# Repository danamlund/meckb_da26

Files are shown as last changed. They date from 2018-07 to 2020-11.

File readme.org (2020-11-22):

A 26-key keyboard with 3d printed case and [[https://github.com/qmk/qmk_firmware][qmk firmware]]

* Features
 - 26 keys
 - Layers within layers
 - Tetris
 - Minesweeper
 - Basic

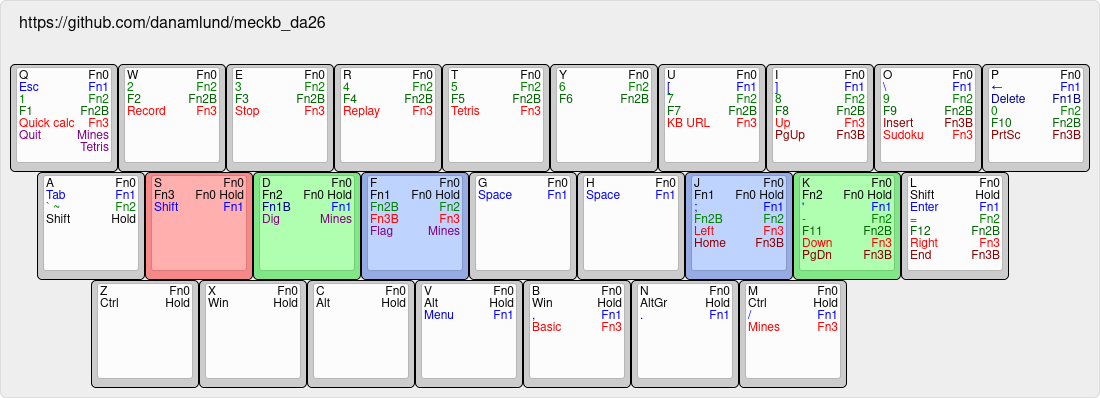
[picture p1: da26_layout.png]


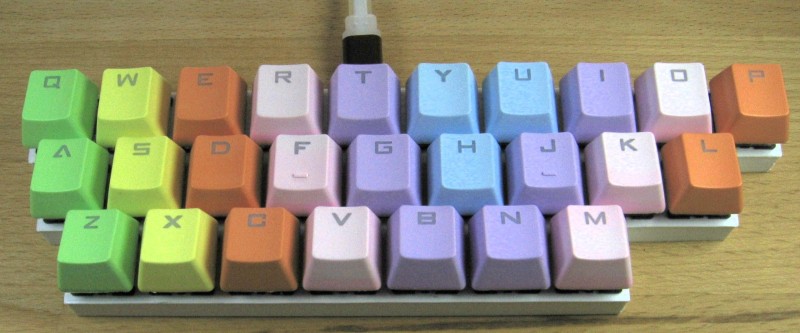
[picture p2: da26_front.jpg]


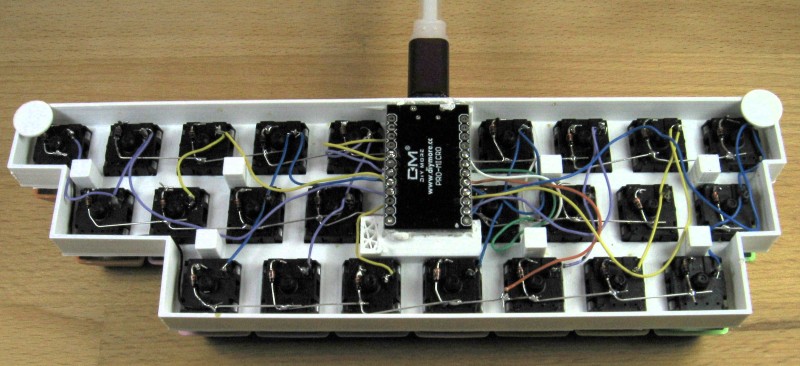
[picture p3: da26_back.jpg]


* Common key combinations
 - ALT F4: C (Alt), K (Fn2), J (Fn2B), R (F4)
 - Ctrl C: Z (Ctrl), C
 - Ctrl Z: M (Ctrl), Z
 - Shift Enter: A (Shift), F (Fn1), L (Enter)
 - AltGr ': N (AltGr), F (Fn1), K (')
 - Alt Tab: C (Alt), J (Fn1), A (Tab)
 - Shift Alt Tab: C (Alt), J (Fn1), L (Shift), A (Tab)
 - Ctrl PgDn: Z (Ctrl), S (Fn3), F (Fn3B), K (PgDn)
 - C-x C-s: Z (Ctrl), X (x), release X, S (s)
 - :q!<enter>: A (Shift), F (Fn1), J (;), release, Q (q), release, F (Fn1), L (Enter)

* Tetris
 - When playing tetris the keyboard is stuck in FN3
 - Use ijkl keys to move/rotate/drop
 - Press ESC to quit

* Minesweeper
 - Use ijkl keys to move cursor around
 - Press d to dig for a mine
 - Press f to flag square as a mine
 - Press Esc to quit
 - 16x16 grid with 40 mines (Intermediate in windows minesweeper)

* Basic
 - [[https://en.wikipedia.org/wiki/Tiny_BASIC][Tiny BASIC]]
 - [[http://hamsterworks.co.nz/mediawiki/index.php/Arduino_Basic][Arduino Basic / Tiny Basic C by Michael Field and Scott Lawrence]]
   - Simpler sibling of [[https://github.com/BleuLlama/TinyBasicPlus][TinyBasic Plus]]
 - Press ESC to break out of infinite loops
 - Type 'bye' to quit
 - Ignores movement keys except for backspace
 - Uses US layout
 - 1024 bytes memory (866 free after reserved variable storage)
 - all numbers are float
 - Executes 1 instruction per 50 ms
 - When typed keys stop working you are out of memory
 - Type 'mem' to see memory left
 - ncurses version in tinybasic_test/
 - quick calc calls basic, stores result in a, and prints it

* keyboard-layout-editor.com
 - http://www.keyboard-layout-editor.com
** All layers in one
#+HTML: <a href="http://www.keyboard-layout-editor.com/##@@_f:5&w:10&d:true;&=https/:////github.com//danamlund//meckb/_da26;&@_f:3&w:2&h:2;&=Q%3Cbr//%3E%3Cfont%20color/=blue%3EEsc%3C//font%3E%3Cbr//%3E%3Cfont%20color/=green%3E1%3C//font%3E%3Cbr//%3E%3Cfont%20color/=darkgreen%3EF1%3C//font%3E%3Cbr//%3E%3Cfont%20color/=red%3EQuick%20calc%3C//font%3E%3Cbr//%3E%3Cfont%20color/=purple%3EQuit%3C//font%3E%0A%0AFn0%3Cbr//%3E%3Cfont%20color/=blue%3EFn1%3C//font%3E%3Cbr//%3E%3Cfont%20color/=green%3EFn2%3C//font%3E%3Cbr//%3E%3Cfont%20color/=darkgreen%3EFn2B%3C//font%3E%3Cbr//%3E%3Cfont%20color/=red%3EFn3%3C//font%3E%3Cbr//%3E%3Cfont%20color/=purple%3EMines%3C//font%3E%3Cbr//%3E%3Cfont%20color/=purple%3ETetris%3C//font%3E&_w:2&h:2;&=W%3Cbr//%3E%3Cfont%20color/=green%3E2%3C//font%3E%3Cbr//%3E%3Cfont%20color/=darkgreen%3EF2%3C//font%3E%3Cbr//%3E%3Cfont%20color/=red%3ERecord%3C//font%3E%0A%0AFn0%3Cbr//%3E%3Cfont%20color/=green%3EFn2%3C//font%3E%3Cbr//%3E%3Cfont%20color/=darkgreen%3EFn2B%3C//font%3E%3Cbr//%3E%3Cfont%20color/=red%3EFn3%3C//font%3E&_w:2&h:2;&=E%3Cbr//%3E%3Cfont%20color/=green%3E3%3C//font%3E%3Cbr//%3E%3Cfont%20color/=darkgreen%3EF3%3C//font%3E%3Cbr//%3E%3Cfont%20color/=red%3EStop%3C//font%3E%0A%0AFn0%3Cbr//%3E%3Cfont%20color/=green%3EFn2%3C//font%3E%3Cbr//%3E%3Cfont%20color/=darkgreen%3EFn2B%3C//font%3E%3Cbr//%3E%3Cfont%20color/=red%3EFn3%3C//font%3E&_w:2&h:2;&=R%3Cbr//%3E%3Cfont%20color/=green%3E4%3C//font%3E%3Cbr//%3E%3Cfont%20color/=darkgreen%3EF4%3C//font%3E%3Cbr//%3E%3Cfont%20color/=red%3EReplay%3C//font%3E%0A%0AFn0%3Cbr//%3E%3Cfont%20color/=green%3EFn2%3C//font%3E%3Cbr//%3E%3Cfont%20color/=darkgreen%3EFn2B%3C//font%3E%3Cbr//%3E%3Cfont%20color/=red%3EFn3%3C//font%3E&_w:2&h:2;&=T%3Cbr//%3E%3Cfont%20color/=green%3E5%3C//font%3E%3Cbr//%3E%3Cfont%20color/=darkgreen%3EF5%3C//font%3E%3Cbr//%3E%3Cfont%20color/=red%3ETetris%3C//font%3E%0A%0AFn0%3Cbr//%3E%3Cfont%20color/=green%3EFn2%3C//font%3E%3Cbr//%3E%3Cfont%20color/=darkgreen%3EFn2B%3C//font%3E%3Cbr//%3E%3Cfont%20color/=red%3EFn3%3C//font%3E&_w:2&h:2;&=Y%3Cbr//%3E%3Cfont%20color/=green%3E6%3C//font%3E%3Cbr//%3E%3Cfont%20color/=darkgreen%3EF6%3C//font%3E%0A%0AFn0%3Cbr//%3E%3Cfont%20color/=green%3EFn2%3C//font%3E%3Cbr//%3E%3Cfont%20color/=darkgreen%3EFn2B%3C//font%3E&_w:2&h:2;&=U%3Cbr//%3E%3Cfont%20color/=blue%3E%5B%3C//font%3E%3Cbr//%3E%3Cfont%20color/=green%3E7%3C//font%3E%3Cbr//%3E%3Cfont%20color/=darkgreen%3EF7%3C//font%3E%3Cbr//%3E%3Cfont%20color/=red%3EKB%20URL%3C//font%3E%0A%0AFn0%3Cbr//%3E%3Cfont%20color/=blue%3EFn1%3C//font%3E%3Cbr//%3E%3Cfont%20color/=green%3EFn2%3C//font%3E%3Cbr//%3E%3Cfont%20color/=darkgreen%3EFn2B%3C//font%3E%3Cbr//%3E%3Cfont%20color/=red%3EFn3%3C//font%3E&_w:2&h:2;&=I%3Cbr//%3E%3Cfont%20color/=blue%3E%5D%3C//font%3E%3Cbr//%3E%3Cfont%20color/=green%3E8%3C//font%3E%3Cbr//%3E%3Cfont%20color/=darkgreen%3EF8%3C//font%3E%3Cbr//%3E%3Cfont%20color/=red%3EUp%3C//font%3E%3Cbr//%3E%3Cfont%20color/=darkred%3EPgUp%3C//font%3E%0A%0AFn0%3Cbr//%3E%3Cfont%20color/=blue%3EFn1%3C//font%3E%3Cbr//%3E%3Cfont%20color/=green%3EFn2%3C//font%3E%3Cbr//%3E%3Cfont%20color/=darkgreen%3EFn2B%3C//font%3E%3Cbr//%3E%3Cfont%20color/=red%3EFn3%3C//font%3E%3Cbr//%3E%3Cfont%20color/=darkred%3EFn3B%3C//font%3E&_w:2&h:2;&=O%3Cbr//%3E%3Cfont%20color/=blue%3E%5C%3C//font%3E%3Cbr//%3E%3Cfont%20color/=green%3E9%3C//font%3E%3Cbr//%3E%3Cfont%20color/=darkgreen%3EF9%3C//font%3E%3Cbr//%3E%3Cfont%20color/=darkred%3EInsert%3C//font%3E%3Cbr//%3E%3Cfont%20color/=red%3ESudoku%3C//font%3E%0A%0AFn0%3Cbr//%3E%3Cfont%20color/=blue%3EFn1%3C//font%3E%3Cbr//%3E%3Cfont%20color/=green%3EFn2%3C//font%3E%3Cbr//%3E%3Cfont%20color/=darkgreen%3EFn2B%3C//font%3E%3Cbr//%3E%3Cfont%20color/=darkred%3EFn3B%3C//font%3E%3Cbr//%3E%3Cfont%20color/=red%3EFn3%3C//font%3E&_w:2&h:2;&=P%3Cbr//%3E%3Cfont%20color/=blue%3E%E2%86%90%3C//font%3E%3Cbr//%3E%3Cfont%20color/=darkblue%3EDelete%3C//font%3E%3Cbr//%3E%3Cfont%20color/=green%3E0%3C//font%3E%3Cbr//%3E%3Cfont%20color/=darkgreen%3EF10%3C//font%3E%3Cbr//%3E%3Cfont%20color/=darkred%3EPrtSc%3C//font%3E%0A%0AFn0%3Cbr//%3E%3Cfont%20color/=blue%3EFn1%3C//font%3E%3Cbr//%3E%3Cfont%20color/=darkblue%3EFn1B%3C//font%3E%3Cbr//%3E%3Cfont%20color/=green%3EFn2%3C//font%3E%3Cbr//%3E%3Cfont%20color/=darkgreen%3EFn2B%3C//font%3E%3Cbr//%3E%3Cfont%20color/=darkred%3EFn3B%3C//font%3E;&@_y:1&x:0.5&w:2&h:2;&=A%3Cbr//%3E%3Cfont%20color/=blue%3ETab%3C//font%3E%3Cbr//%3E%3Cfont%20color/=green%3E%60%20~%3C//font%3E%3Cbr//%3EShift%0A%0AFn0%3Cbr//%3E%3Cfont%20color/=blue%3EFn1%3C//font%3E%3Cbr//%3E%3Cfont%20color/=green%3EFn2%3C//font%3E%3Cbr%3EHold&_w:2&h:2&c=#f78888;&=S%3Cbr//%3EFn3%3Cbr//%3E%3Cfont%20color/=blue%3EShift%3C//font%3E%0A%0AFn0%3Cbr//%3EFn0%20Hold%3Cbr//%3E%3Cfont%20color/=blue%3EFn1%3C//font%3E&_w:2&h:2&c=#81e685;&=D%3Cbr//%3EFn2%3Cbr//%3E%3Cfont%20color/=darkblue%3EFn1B%3C//font%3E%3Cbr//%3E%3Cfont%20color/=purple%3EDig%3C//font%3E%0A%0AFn0%3Cbr//%3EFn0%20Hold%3Cbr//%3E%3Cfont%20color/=blue%3EFn1%3C//font%3E%3Cbr//%3E%3Cfont%20color/=purple%3EMines%3C//font%3E&_w:2&h:2&c=#96abe3;&=F%3Cbr//%3EFn1%3Cbr//%3E%3Cfont%20color/=green%3EFn2B%3C//font%3E%3Cbr//%3E%3Cfont%20color/=red%3EFn3B%3C//font%3E%3Cbr//%3E%3Cfont%20color/=purple%3EFlag%3C//font%3E%0A%0AFn0%3Cbr//%3EFn0%20Hold%3Cbr//%3E%3Cfont%20color/=green%3EFn2%3C//font%3E%3Cbr//%3E%3Cfont%20color/=red%3EFn3%3C//font%3E%3Cbr//%3E%3Cfont%20color/=purple%3EMines%3C//font%3E&_w:2&h:2&c=#cccccc;&=G%3Cbr//%3E%3Cfont%20color/=blue%3ESpace%3C//font%3E%0A%0AFn0%3Cbr//%3E%3Cfont%20color/=blue%3EFn1%3C//font%3E&_w:2&h:2;&=H%3Cbr//%3E%3Cfont%20color/=blue%3ESpace%3C//font%3E%0A%0AFn0%3Cbr//%3E%3Cfont%20color/=blue%3EFn1%3C//font%3E&_w:2&h:2&c=#96abe3;&=J%3Cbr//%3EFn1%3Cbr//%3E%3Cfont%20color/=blue%3E/;%3C//font%3E%3Cbr//%3E%3Cfont%20color/=green%3EFn2B%3C//font%3E%3Cbr//%3E%3Cfont%20color/=red%3ELeft%3C//font%3E%3Cbr//%3E%3Cfont%20color/=darkred%3EHome%3C//font%3E%0A%0AFn0%3Cbr//%3EFn0%20Hold%3Cbr//%3E%3Cfont%20color/=blue%3EFn1%3C//font%3E%3Cbr//%3E%3Cfont%20color/=green%3EFn2%3C//font%3E%3Cbr//%3E%3Cfont%20color/=red%3EFn3%3C//font%3E%3Cbr//%3E%3Cfont%20color/=darkred%3EFn3B%3C//font%3E&_w:2&h:2&c=#81e685;&=K%3Cbr//%3EFn2%3Cbr//%3E%3Cfont%20color/=blue%3E'%3C//font%3E%3Cbr//%3E%3Cfont%20color/=green%3E-%3C//font%3E%3Cbr//%3E%3Cfont%20color/=darkgreen%3EF11%3C//font%3E%3Cbr//%3E%3Cfont%20color/=red%3EDown%3C//font%3E%3Cbr//%3E%3Cfont%20color/=darkred%3EPgDn%3C//font%3E%0A%0AFn0%3Cbr//%3EFn0%20Hold%3Cbr//%3E%3Cfont%20color/=blue%3EFn1%3C//font%3E%3Cbr//%3E%3Cfont%20color/=green%3EFn2%3C//font%3E%3Cbr//%3E%3Cfont%20color/=darkgreen%3EFn2B%3C//font%3E%3Cbr//%3E%3Cfont%20color/=red%3EFn3%3C//font%3E%3Cbr//%3E%3Cfont%20color/=darkred%3EFn3B%3C//font%3E&_w:2&h:2&c=#cccccc;&=L%3Cbr//%3EShift%3Cbr//%3E%3Cfont%20color/=blue%3EEnter%3C//font%3E%3Cbr//%3E%3Cfont%20color/=green%3E/=%3C//font%3E%3Cbr//%3E%3Cfont%20color/=darkgreen%3EF12%3C//font%3E%3Cbr//%3E%3Cfont%20color/=red%3ERight%3C//font%3E%3Cbr//%3E%3Cfont%20color/=darkred%3EEnd%3C//font%3E%0A%0AFn0%3Cbr//%3EHold%3Cbr//%3E%3Cfont%20color/=blue%3EFn1%3C//font%3E%3Cbr//%3E%3Cfont%20color/=green%3EFn2%3C//font%3E%3Cbr//%3E%3Cfont%20color/=darkgreen%3EFn2B%3C//font%3E%3Cbr//%3E%3Cfont%20color/=red%3EFn3%3C//font%3E%3Cbr//%3E%3Cfont%20color/=darkred%3EFn3B%3C//font%3E;&@_y:1&x:1.5&w:2&h:2;&=Z%3Cbr//%3ECtrl%0A%0AFn0%3Cbr//%3EHold&_w:2&h:2;&=X%3Cbr//%3EWin%0A%0AFn0%3Cbr//%3EHold&_w:2&h:2;&=C%3Cbr//%3EAlt%0A%0AFn0%3Cbr//%3EHold&_w:2&h:2;&=V%3Cbr//%3EAlt%3Cbr//%3E%3Cfont%20color/=blue%3EMenu%3C//font%3E%0A%0AFn0%3Cbr//%3EHold%3Cbr//%3E%3Cfont%20color/=blue%3EFn1%3C//font%3E&_w:2&h:2;&=B%3Cbr//%3EWin%3Cbr//%3E%3Cfont%20color/=blue%3E,%3C//font%3E%3Cbr//%3E%3Cfont%20color/=red%3EBasic%3C//font%3E%0A%0AFn0%3Cbr//%3EHold%3Cbr//%3E%3Cfont%20color/=blue%3EFn1%3C//font%3E%3Cbr//%3E%3Cfont%20color/=red%3EFn3%3C//font%3E&_w:2&h:2;&=N%3Cbr//%3EAltGr%3Cbr//%3E%3Cfont%20color/=blue%3E.%3C//font%3E%0A%0AFn0%3Cbr//%3EHold%3Cbr//%3E%3Cfont%20color/=blue%3EFn1%3C//font%3E&_w:2&h:2;&=M%3Cbr//%3ECtrl%3Cbr//%3E%3Cfont%20color/=blue%3E//%3C//font%3E%3Cbr//%3E%3Cfont%20color/=red%3EMines%3C//font%3E%0A%0AFn0%3Cbr//%3EHold%3Cbr//%3E%3Cfont%20color/=blue%3EFn1%3C//font%3E%3Cbr//%3E%3Cfont%20color/=red%3EFn3%3C//font%3E">da26 keyboard-layout-editor.com</a>
#+BEGIN_EXAMPLE
[{f:5,w:10,d:true},"https://github.com/danamlund/meckb_da26"],
[{f:3,w:2,h:2},"Q<br/><font color=blue>Esc</font><br/><font color=green>1</font><br/><font color=darkgreen>F1</font><br/><font color=red>Quick calc</font><br/><font color=purple>Quit</font>\n\nFn0<br/><font color=blue>Fn1</font><br/><font color=green>Fn2</font><br/><font color=darkgreen>Fn2B</font><br/><font color=red>Fn3</font><br/><font color=purple>Mines</font><br/><font color=purple>Tetris</font>",
{w:2,h:2},"W<br/><font color=green>2</font><br/><font color=darkgreen>F2</font><br/><font color=red>Record</font>\n\nFn0<br/><font color=green>Fn2</font><br/><font color=darkgreen>Fn2B</font><br/><font color=red>Fn3</font>",
{w:2,h:2},"E<br/><font color=green>3</font><br/><font color=darkgreen>F3</font><br/><font color=red>Stop</font>\n\nFn0<br/><font color=green>Fn2</font><br/><font color=darkgreen>Fn2B</font><br/><font color=red>Fn3</font>",
{w:2,h:2},"R<br/><font color=green>4</font><br/><font color=darkgreen>F4</font><br/><font color=red>Replay</font>\n\nFn0<br/><font color=green>Fn2</font><br/><font color=darkgreen>Fn2B</font><br/><font color=red>Fn3</font>",
{w:2,h:2},"T<br/><font color=green>5</font><br/><font color=darkgreen>F5</font><br/><font color=red>Tetris</font>\n\nFn0<br/><font color=green>Fn2</font><br/><font color=darkgreen>Fn2B</font><br/><font color=red>Fn3</font>",
{w:2,h:2},"Y<br/><font color=green>6</font><br/><font color=darkgreen>F6</font>\n\nFn0<br/><font color=green>Fn2</font><br/><font color=darkgreen>Fn2B</font>",
{w:2,h:2},"U<br/><font color=blue>[</font><br/><font color=green>7</font><br/><font color=darkgreen>F7</font><br/><font color=red>KB URL</font>\n\nFn0<br/><font color=blue>Fn1</font><br/><font color=green>Fn2</font><br/><font color=darkgreen>Fn2B</font><br/><font color=red>Fn3</font>",
{w:2,h:2},"I<br/><font color=blue>]</font><br/><font color=green>8</font><br/><font color=darkgreen>F8</font><br/><font color=red>Up</font><br/><font color=darkred>PgUp</font>\n\nFn0<br/><font color=blue>Fn1</font><br/><font color=green>Fn2</font><br/><font color=darkgreen>Fn2B</font><br/><font color=red>Fn3</font><br/><font color=darkred>Fn3B</font>",
{w:2,h:2},"O<br/><font color=blue>\\</font><br/><font color=green>9</font><br/><font color=darkgreen>F9</font><br/><font color=darkred>Insert</font><br/><font color=red>Sudoku</font>\n\nFn0<br/><font color=blue>Fn1</font><br/><font color=green>Fn2</font><br/><font color=darkgreen>Fn2B</font><br/><font color=darkred>Fn3B</font><br/><font color=red>Fn3</font>",
{w:2,h:2},"P<br/><font color=blue>←</font><br/><font color=darkblue>Delete</font><br/><font color=green>0</font><br/><font color=darkgreen>F10</font><br/><font color=darkred>PrtSc</font>\n\nFn0<br/><font color=blue>Fn1</font><br/><font color=darkblue>Fn1B</font><br/><font color=green>Fn2</font><br/><font color=darkgreen>Fn2B</font><br/><font color=darkred>Fn3B</font>"],

[{y:1,x:0.5,w:2,h:2},"A<br/><font color=blue>Tab</font><br/><font color=green>` ~</font><br/>Shift\n\nFn0<br/><font color=blue>Fn1</font><br/><font color=green>Fn2</font><br>Hold",
{w:2,h:2,c:"#f78888"},"S<br/>Fn3<br/><font color=blue>Shift</font>\n\nFn0<br/>Fn0 Hold<br/><font color=blue>Fn1</font>",
{w:2,h:2,c:"#81e685"},"D<br/>Fn2<br/><font color=darkblue>Fn1B</font><br/><font color=purple>Dig</font>\n\nFn0<br/>Fn0 Hold<br/><font color=blue>Fn1</font><br/><font color=purple>Mines</font>",
{w:2,h:2,c:"#96abe3"},"F<br/>Fn1<br/><font color=green>Fn2B</font><br/><font color=red>Fn3B</font><br/><font color=purple>Flag</font>\n\nFn0<br/>Fn0 Hold<br/><font color=green>Fn2</font><br/><font color=red>Fn3</font><br/><font color=purple>Mines</font>",
{w:2,h:2,c:"#cccccc"},"G<br/><font color=blue>Space</font>\n\nFn0<br/><font color=blue>Fn1</font>",
{w:2,h:2},"H<br/><font color=blue>Space</font>\n\nFn0<br/><font color=blue>Fn1</font>",
{w:2,h:2,c:"#96abe3"},"J<br/>Fn1<br/><font color=blue>;</font><br/><font color=green>Fn2B</font><br/><font color=red>Left</font><br/><font color=darkred>Home</font>\n\nFn0<br/>Fn0 Hold<br/><font color=blue>Fn1</font><br/><font color=green>Fn2</font><br/><font color=red>Fn3</font><br/><font color=darkred>Fn3B</font>",
{w:2,h:2,c:"#81e685"},"K<br/>Fn2<br/><font color=blue>'</font><br/><font color=green>-</font><br/><font color=darkgreen>F11</font><br/><font color=red>Down</font><br/><font color=darkred>PgDn</font>\n\nFn0<br/>Fn0 Hold<br/><font color=blue>Fn1</font><br/><font color=green>Fn2</font><br/><font color=darkgreen>Fn2B</font><br/><font color=red>Fn3</font><br/><font color=darkred>Fn3B</font>",
{w:2,h:2,c:"#cccccc"},"L<br/>Shift<br/><font color=blue>Enter</font><br/><font color=green>=</font><br/><font color=darkgreen>F12</font><br/><font color=red>Right</font><br/><font color=darkred>End</font>\n\nFn0<br/>Hold<br/><font color=blue>Fn1</font><br/><font color=green>Fn2</font><br/><font color=darkgreen>Fn2B</font><br/><font color=red>Fn3</font><br/><font color=darkred>Fn3B</font>"],

[{y:1,x:1.5,w:2,h:2},"Z<br/>Ctrl\n\nFn0<br/>Hold",
{w:2,h:2},"X<br/>Win\n\nFn0<br/>Hold",
{w:2,h:2},"C<br/>Alt\n\nFn0<br/>Hold",
{w:2,h:2},"V<br/>Alt<br/><font color=blue>Menu</font>\n\nFn0<br/>Hold<br/><font color=blue>Fn1</font>",
{w:2,h:2},"B<br/>Win<br/><font color=blue>,</font><br/><font color=red>Basic</font>\n\nFn0<br/>Hold<br/><font color=blue>Fn1</font><br/><font color=red>Fn3</font>",
{w:2,h:2},"N<br/>AltGr<br/><font color=blue>.</font>\n\nFn0<br/>Hold<br/><font color=blue>Fn1</font>",
{w:2,h:2},"M<br/>Ctrl<br/><font color=blue>/</font><br/><font color=red>Mines</font>\n\nFn0<br/>Hold<br/><font color=blue>Fn1</font><br/><font color=red>Fn3</font>"]
#+END_EXAMPLE
** One per layer
#+HTML: <a href="http://www.keyboard-layout-editor.com/##@@_f:5&w:10&d:true;&=https/:////github.com//danamlund//meckb/_da26;&@_f:3&w:2.5;&=Tab%20to%20activate%0ARelease%20to%20activate%0A%0A%0A%0A%0AHold%20to%20activate;&@_f:10&w:10&d:true;&=Layer%200;&@_y:-0.5&f:3;&=Q&=W&=E&=R&=T&=Y&=U&=I&=O&=P;&@_x:0.25;&=A%0A%0A%0A%0A%0A%0AShift&_c=#f78888;&=S%0A%0A%0A%0A%0A%0AFn3&_c=#81e685;&=D%0A%0A%0A%0A%0A%0AFn2&_c=#96abe3;&=F%0A%0A%0A%0A%0A%0AFn1&_c=#cccccc;&=G&=H&_c=#96abe3;&=J%0A%0A%0A%0A%0A%0AFn1&_c=#81e685;&=K%0A%0A%0A%0A%0A%0AFn2&_c=#cccccc;&=L%0A%0A%0A%0A%0A%0AShfit;&@_x:0.75;&=Z%0A%0A%0A%0A%0A%0ACtrl&=X%0A%0A%0A%0A%0A%0AWin&=C%0A%0A%0A%0A%0A%0AAlt&=V%0A%0A%0A%0A%0A%0AAlt&=B%0A%0A%0A%0A%0A%0AWin&=N%0A%0A%0A%0A%0A%0AAltGr&=M%0A%0A%0A%0A%0A%0ACtrl;&@_y:0.5&f:10&w:10&d:true;&=Layer%201;&@_y:-0.5&c=#96abe3&f:3;&=ESC&_c=#cccccc&a:7;&=&=&=&=&=&_c=#96abe3&a:4;&=%5B&=%5D&=%5C&=%E2%86%90;&@_x:0.25;&=Tab%0A%0A%0A%0A%0A%0AShift&_c=#cccccc&a:6;&=Shift&_c=#735fed;&=Fn1B&_c=#cccccc&a:4;&=%0AFn0&_c=#96abe3;&=Space&=Space&=/;%0AFn0&='&=Enter;&@_x:0.75&c=#cccccc;&=Ctrl&=Win&=Alt&_c=#96abe3;&=Menu&=,&=.%0A%0A%0A%0A%0A%0AAltGr&=//%0A%0A%0A%0A%0A%0ACtrl;&@_y:0.5&f:10&w:10&d:true;&=Layer%201%20B;&@_y:-0.5&c=#cccccc&a:7&f:3;&=&=&=&=&=&=&=&=&=&_c=#735fed&a:4;&=Delete;&@_x:0.25&c=#cccccc;&=Shift&_a:7;&=&_c=#96abe3&a:4;&=%0AFn1&_c=#cccccc;&=%0AFn0&_a:7;&=&=&_a:4;&=%0AFn0&_a:7;&=&_a:4;&=Shift;&@_x:0.75;&=Ctrl&=Win&=Alt&_a:7;&=&=&_a:4;&=AltGr&=Ctrl;&@_y:0.5&f:10&w:10&d:true;&=Layer%202;&@_y:-0.5&c=#81e685&f:3;&=1&=2&=3&=4&=5&=6&=7&=8&=9&=0;&@_x:0.25;&=%60%0A%0A%0A%0A%0A%0AShift&_c=#cccccc&a:7;&=&_a:4;&=%0AFn0&_c=#64b366&a:6;&=Fn2B&_c=#cccccc&a:7;&=&=&_c=#64b366&a:6;&=Fn2B&_c=#81e685&a:4;&=-%0AFn0&=/=%0A%0A%0A%0A%0A%0AShift;&@_x:0.75&c=#cccccc;&=Ctrl&=Win&=Alt&_a:7;&=&=&_a:4;&=AltGr&=Ctrl;&@_y:0.5&f:10&w:10&d:true;&=Layer%202%20B;&@_y:-0.5&c=#64b366&f:3;&=F1&=F2&=F3&=F4&=F5&=F6&=F7&=F8&=F9&=F10;&@_x:0.25&c=#cccccc;&=Shfit&_a:7;&=&_a:4;&=%0AFn0&_c=#81e685;&=%0AFn2&_c=#cccccc&a:7;&=&=&_c=#81e685&a:4;&=%0AFn2&_c=#64b366;&=F11%0AFn0&=F12%0A%0A%0A%0A%0A%0AShift;&@_x:0.75&c=#cccccc;&=Ctrl&=Win&=Alt&_a:7;&=&=&_a:4;&=AltGr&=Ctrl;&@_y:0.5&f:10&w:10&d:true;&=Layer%203;&@_y:-0.5&c=#f78888&f:3;&=Quick%20calc&=Record&=Stop&=Replay&_c=#f78888&a:4;&=Tetris&_c=#cccccc&a:7;&=&_a:4;&=URL&_c=#f78888;&=Up&_c=#cccccc&a:7;&_c=#f78888&a:4;&=Sudoku&_c=#cccccc&a:7;&=;&@_x:0.25&a:4;&=Shift&=%0AFn0&_a:7;&=&_c=#b85353&a:6;&=Fn3B&_c=#cccccc&a:7;&=&=&_c=#f78888&a:4;&=Left&=Down&=Right;&@_x:0.75&c=#cccccc;&=Ctrl&=Win&=Alt&_a:7;&=&_c=#f78888&a:4;&=Basic&_c=#cccccc;&=AltGr&_c=#d99ae3;&=Mines;&@_y:0.5&c=#cccccc&f:10&w:10&d:true;&=Layer%203%20B;&@_y:-0.5&a:7&f:3;&=&=&=&=&=&=&=&_c=#b85353&a:4;&=PgUp&=Insert&=PrtSc;&@_x:0.25&c=#cccccc;&=Shift&=%0AFn0&_a:7;&=&_c=#f78888&a:4;&=%0AFn3&_c=#cccccc&a:7;&=&=&_c=#b85353&a:4;&=Home&=PgDn&=End;&@_x:0.75&c=#cccccc;&=Ctrl&=Win&=Alt&_a:7;&=&=&_a:4;&=AltGr&=Ctrl;&@_y:0.5&c=#cccccc&f:10&w:10&d:true;&=Minesweeper;&@_y:-0.5&a:4&f:3&c=#d99ae3;&=Quit&_c=#cccccc;&=&=&=&=&=&=&_c=#d99ae3&a:4;&=Up&_c=#cccccc;&=&=;&@_x:0.25&c=#cccccc;&=&=&_c=#d99ae3&a:4;&=Dig&=Flag&_c=#cccccc;&=&=&_c=#d99ae3&a:4;&=Left&=Down&=Right;&@_x:0.75&c=#cccccc;&=&=&=&_a:7;&=&=&_a:4;&=&=">da26 keyboard-layout-editor.com</a>
#+BEGIN_EXAMPLE
[{f:5,w:10,d:true},"https://github.com/danamlund/meckb_da26"],
[{f:3,w:2.5},"Tab to activate\nRelease to activate\n\n\n\n\nHold to activate"],
[{f:10,w:10,d:true},"Layer 0"],
[{y:-0.5,f:3},"Q","W","E","R","T","Y","U","I","O","P"],
[{x:0.25},"A\n\n\n\n\n\nShift",{c:"#f78888"},"S\n\n\n\n\n\nFn3",{c:"#81e685"},"D\n\n\n\n\n\nFn2",{c:"#96abe3"},"F\n\n\n\n\n\nFn1",{c:"#cccccc"},"G","H",{c:"#96abe3"},"J\n\n\n\n\n\nFn1",{c:"#81e685"},"K\n\n\n\n\n\nFn2",{c:"#cccccc"},"L\n\n\n\n\n\nShfit"],
[{x:0.75},"Z\n\n\n\n\n\nCtrl","X\n\n\n\n\n\nWin","C\n\n\n\n\n\nAlt","V\n\n\n\n\n\nAlt","B\n\n\n\n\n\nWin","N\n\n\n\n\n\nAltGr","M\n\n\n\n\n\nCtrl"],
[{y:0.5,f:10,w:10,d:true},"Layer 1"],
[{y:-0.5,c:"#96abe3",f:3},"ESC",{c:"#cccccc",a:7},"","","","","",{c:"#96abe3",a:4},"[","]","\\","←"],
[{x:0.25},"Tab\n\n\n\n\n\nShift",{c:"#cccccc",a:6},"Shift",{c:"#735fed"},"Fn1B",{c:"#cccccc",a:4},"\nFn0",{c:"#96abe3"},"Space","Space",";\nFn0","'","Enter"],
[{x:0.75,c:"#cccccc"},"Ctrl","Win","Alt",{c:"#96abe3"},"Menu",",",".\n\n\n\n\n\nAltGr","/\n\n\n\n\n\nCtrl"],
[{y:0.5,f:10,w:10,d:true},"Layer 1 B"],
[{y:-0.5,c:"#cccccc",a:7,f:3},"","","","","","","","","",{c:"#735fed",a:4},"Delete"],
[{x:0.25,c:"#cccccc"},"Shift",{a:7},"",{c:"#96abe3",a:4},"\nFn1",{c:"#cccccc"},"\nFn0",{a:7},"","",{a:4},"\nFn0",{a:7},"",{a:4},"Shift"],
[{x:0.75},"Ctrl","Win","Alt",{a:7},"","",{a:4},"AltGr","Ctrl"],
[{y:0.5,f:10,w:10,d:true},"Layer 2"],
[{y:-0.5,c:"#81e685",f:3},"1","2","3","4","5","6","7","8","9","0"],
[{x:0.25},"`\n\n\n\n\n\nShift",{c:"#cccccc",a:7},"",{a:4},"\nFn0",{c:"#64b366",a:6},"Fn2B",{c:"#cccccc",a:7},"","",{c:"#64b366",a:6},"Fn2B",{c:"#81e685",a:4},"-\nFn0","=\n\n\n\n\n\nShift"],
[{x:0.75,c:"#cccccc"},"Ctrl","Win","Alt",{a:7},"","",{a:4},"AltGr","Ctrl"],
[{y:0.5,f:10,w:10,d:true},"Layer 2 B"],
[{y:-0.5,c:"#64b366",f:3},"F1","F2","F3","F4","F5","F6","F7","F8","F9","F10"],
[{x:0.25,c:"#cccccc"},"Shfit",{a:7},"",{a:4},"\nFn0",{c:"#81e685"},"\nFn2",{c:"#cccccc",a:7},"","",{c:"#81e685",a:4},"\nFn2",{c:"#64b366"},"F11\nFn0","F12\n\n\n\n\n\nShift"],
[{x:0.75,c:"#cccccc"},"Ctrl","Win","Alt",{a:7},"","",{a:4},"AltGr","Ctrl"],
[{y:0.5,f:10,w:10,d:true},"Layer 3"],
[{y:-0.5,c:"#f78888",f:3},"Quick calc","Record","Stop","Replay",{c:"#f78888",a:4},"Tetris",{c:"#cccccc",a:7},"",{a:4},"URL",{c:"#f78888"},"Up",{c:"#cccccc",a:7},{c:"#f78888",a:4},"Sudoku",{c:"#cccccc",a:7},""],
[{x:0.25,a:4},"Shift","\nFn0",{a:7},"",{c:"#b85353",a:6},"Fn3B",{c:"#cccccc",a:7},"","",{c:"#f78888",a:4},"Left","Down","Right"],
[{x:0.75,c:"#cccccc"},"Ctrl","Win","Alt",{a:7},"",{c:"#f78888",a:4},"Basic",{c:"#cccccc"},"AltGr",{c:"#d99ae3"},"Mines"],
[{y:0.5,c:"#cccccc",f:10,w:10,d:true},"Layer 3 B"],
[{y:-0.5,a:7,f:3},"","","","","","","",{c:"#b85353",a:4},"PgUp","Insert","PrtSc"],
[{x:0.25,c:"#cccccc"},"Shift","\nFn0",{a:7},"",{c:"#f78888",a:4},"\nFn3",{c:"#cccccc",a:7},"","",{c:"#b85353",a:4},"Home","PgDn","End"],
[{x:0.75,c:"#cccccc"},"Ctrl","Win","Alt",{a:7},"","",{a:4},"AltGr","Ctrl"],
[{y:0.5,c:"#cccccc",f:10,w:10,d:true},"Minesweeper"],
[{y:-0.5,a:7,f:3,a:4,c:"#d99ae3"},"Quit",{c:"#cccccc"},"","","","","","",{c:"#d99ae3",a:4},"Up",{c:"#cccccc"},"",""],
[{x:0.25,c:"#cccccc"},"","",{c:"#d99ae3",a:4},"Dig","Flag",{c:"#cccccc"},"","",{c:"#d99ae3",a:4},"Left","Down","Right"],
[{x:0.75,c:"#cccccc"},"","","",{a:7},"","",{a:4},"",""]
#+END_EXAMPLE

* Components
 - [[https://www.ebay.com/sch/i.html?_nkw=rainbow+caps+mechanical][Rainbow keycaps]]
 - [[https://www.ebay.com/sch/i.html?_nkw=green+mechanical+switch+10pcs][Green gateron mechanical switches]]
 - [[https://www.ebay.com/sch/i.html?_nkw=pro+micro][Pro micro]]
   - The 3d model is designed for the slim and thin blue boards. But I
     ran out of those, so I cut the case to fit one of the fat and
     wide black boards.
 - [[https://www.ebay.com/sch/i.html?_nkw=single+core+wire+colors&_sop=15][Single core wires]]
 - [[https://www.ebay.com/sch/i.html?_nkw=in4148+100pcs+-smt&_sop=15][IN4148 diodes]]

* Bugs
 - QMK firmware "key if tab, other key if hold" does not always know
   what you are thinking.

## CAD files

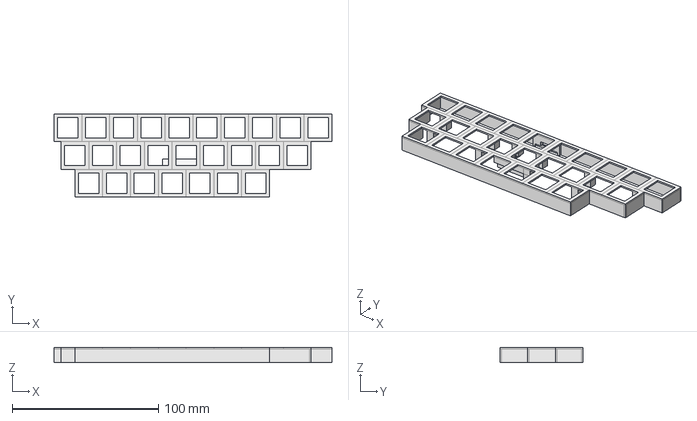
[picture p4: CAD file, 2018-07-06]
3dmodel/meckb_da26.fcstd
190.0 x 57.0 x 10.0 mm

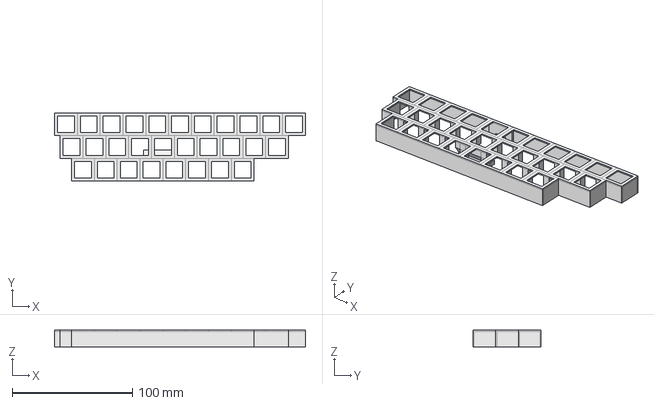
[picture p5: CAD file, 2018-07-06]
3dmodel/meckb_da26_14mm_height.fcstd
209.0 x 57.0 x 14.0 mm

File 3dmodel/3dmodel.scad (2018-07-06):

hole=14;
socket=19;
rim=(socket - hole) / 2;
holeHeight=1;
socketHeight=10;

row2x = socket * 0.25;
row3x = socket * 0.75;
    

module key(x, y) {
    translate([x, y, 0]) {
        translate ([0, 0, socketHeight - holeHeight]) {
            difference() {
                cube ([socket, socket, holeHeight]);
                translate ([rim, rim, 0]) {
                    cube ([hole, hole, holeHeight]);
                }
            }
        }
    }
}

module legs(startx, y, endx, width, length) {
    for (x = [startx : 2*(hole + rim*width) : endx] ) {
        translate ([x, y, 0]) {
            cube ([rim * width, rim * length, socketHeight - holeHeight]);
        }
    }
}

union() {
    for (i = [0 : 9]) {
        key(i * socket, 0);
    }
    for (i = [0 : 8]) {
        key(row2x + i * socket, -socket);
    }
    for (i = [0 : 6]) {
        key(row3x + i * socket, -socket*2);
    }
}

union() {
    legs(hole+rim, -rim, 9*socket, 2, 2);
    legs(hole+rim + row2x, -rim - socket, 8*socket, 2, 2);
}

edge=1;
union() {
    translate ([0, socket - edge, 0]) {
        cube ([10*socket, edge, socketHeight - holeHeight]);
    }
    translate ([0, 0, 0]) {
        cube ([row2x, edge, socketHeight - holeHeight]);
    }
    translate ([row2x + (9 * socket), 0, 0]) {
        cube ([socket - row2x, edge, socketHeight - holeHeight]);
    }
    translate ([row2x, -socket, 0]) {
        cube ([row3x - row2x, edge, socketHeight - holeHeight]);
    }
    translate ([row3x + 7*socket, -socket, 0]) {
        cube ([row3x - row2x + socket, edge, socketHeight - holeHeight]);
    }
    translate ([row3x, -2*socket, 0]) {
        cube ([7*socket, edge, socketHeight - holeHeight]);
    }

    translate ([0, edge, 0]) {
        cube ([edge, socket - 2 * edge, socketHeight - holeHeight]);
    }
    translate ([socket*10 - edge, edge, 0]) {
        cube ([edge, socket - 2 * edge, socketHeight - holeHeight]);
    }

    translate ([row2x, - socket + edge, 0]) {
        cube ([edge, socket, socketHeight - holeHeight]);
    }
    translate ([row2x + 9*socket - edge, - socket, 0]) {
        cube ([edge, socket + edge, socketHeight - holeHeight]);
    }

    translate ([row3x, - 2*socket + edge, 0]) {
        cube ([edge, socket, socketHeight - holeHeight]);
    }
    translate ([row3x + 7*socket - edge, - 2*socket + edge, 0]) {
        cube ([edge, socket, socketHeight - holeHeight]);
    }
}

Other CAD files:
3dmodel/meckb_da26.stl

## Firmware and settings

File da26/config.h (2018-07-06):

/*
Copyright 2018 dan amlund

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
You should have received a copy of the GNU General Public License
along with this program.  If not, see <http://www.gnu.org/licenses/>.
*/

#ifndef CONFIG_H
#define CONFIG_H

#include "config_common.h"

/* USB Device descriptor parameter */
#define VENDOR_ID       0xFEED
#define PRODUCT_ID      0x6062
#define DEVICE_VER      0xABC2
#define MANUFACTURER    danamlund
#define PRODUCT         da26
#define DESCRIPTION     26 key keyboard

/* key matrix size */
#define MATRIX_ROWS 3
#define MATRIX_COLS 9

/*
 * Keyboard Matrix Assignments
 *
 * Change this to how you wired your keyboard
 * COLS: AVR pins used for columns, left to right
 * ROWS: AVR pins used for rows, top to bottom
 * DIODE_DIRECTION: COL2ROW = COL = Anode (+), ROW = Cathode (-, marked on diode)
 *                  ROW2COL = ROW = Anode (+), COL = Cathode (-, marked on diode)
 *
*/
// pro micro: 2, 3, 4
#define MATRIX_ROW_PINS { D1, D0, D4 } 
// pro micro: 5, 6, 7, 8,  A3, A2, A1, A0, 15
#define MATRIX_COL_PINS { C6, D7, E6, B4,  F4, F5, F6, F7, B1 } 
#define UNUSED_PINS

/* COL2ROW, ROW2COL, or CUSTOM_MATRIX */
#define DIODE_DIRECTION COL2ROW

// #define BACKLIGHT_PIN B7
// #define BACKLIGHT_BREATHING
// #define BACKLIGHT_LEVELS 3


/* Debounce reduces chatter (unintended double-presses) - set 0 if debouncing is not needed */
#define DEBOUNCING_DELAY 5

/* define if matrix has ghost (lacks anti-ghosting diodes) */
//#define MATRIX_HAS_GHOST

/* number of backlight levels */

/* Mechanical locking support. Use KC_LCAP, KC_LNUM or KC_LSCR instead in keymap */
#define LOCKING_SUPPORT_ENABLE
/* Locking resynchronize hack */
#define LOCKING_RESYNC_ENABLE

/* If defined, GRAVE_ESC will always act as ESC when CTRL is held.
 * This is userful for the Windows task manager shortcut (ctrl+shift+esc).
 */
// #define GRAVE_ESC_CTRL_OVERRIDE

/*
 * Force NKRO
 *
 * Force NKRO (nKey Rollover) to be enabled by default, regardless of the saved
 * state in the bootmagic EEPROM settings. (Note that NKRO must be enabled in the
 * makefile for this to work.)
 *
 * If forced on, NKRO can be disabled via magic key (default = LShift+RShift+N)
 * until the next keyboard reset.
 *
 * NKRO may prevent your keystrokes from being detected in the BIOS, but it is
 * fully operational during normal computer usage.
 *
 * For a less heavy-handed approach, enable NKRO via magic key (LShift+RShift+N)
 * or via bootmagic (hold SPACE+N while plugging in the keyboard). Once set by
 * bootmagic, NKRO mode will always be enabled until it is toggled again during a
 * power-up.
 *
 */
//#define FORCE_NKRO

/*
 * Magic Key Options
 *
 * Magic keys are hotkey commands that allow control over firmware functions of
 * the keyboard. They are best used in combination with the HID Listen program,
 * found here: https://www.pjrc.com/teensy/hid_listen.html
 *
 * The options below allow the magic key functionality to be changed. This is
 * useful if your keyboard/keypad is missing keys and you want magic key support.
 *
 */

/* key combination for magic key command */
#define IS_COMMAND() ( \
    keyboard_report->mods == (MOD_BIT(KC_LSHIFT) | MOD_BIT(KC_RSHIFT)) \
)

/* control how magic key switches layers */
//#define MAGIC_KEY_SWITCH_LAYER_WITH_FKEYS  true
//#define MAGIC_KEY_SWITCH_LAYER_WITH_NKEYS  true
//#define MAGIC_KEY_SWITCH_LAYER_WITH_CUSTOM false

/* override magic key keymap */
//#define MAGIC_KEY_SWITCH_LAYER_WITH_FKEYS
//#define MAGIC_KEY_SWITCH_LAYER_WITH_NKEYS
//#define MAGIC_KEY_SWITCH_LAYER_WITH_CUSTOM
//#define MAGIC_KEY_HELP1          H
//#define MAGIC_KEY_HELP2          SLASH
//#define MAGIC_KEY_DEBUG          D
//#define MAGIC_KEY_DEBUG_MATRIX   X
//#define MAGIC_KEY_DEBUG_KBD      K
//#define MAGIC_KEY_DEBUG_MOUSE    M
//#define MAGIC_KEY_VERSION        V
//#define MAGIC_KEY_STATUS         S
//#define MAGIC_KEY_CONSOLE        C
//#define MAGIC_KEY_LAYER0_ALT1    ESC
//#define MAGIC_KEY_LAYER0_ALT2    GRAVE
//#define MAGIC_KEY_LAYER0         0
//#define MAGIC_KEY_LAYER1         1
//#define MAGIC_KEY_LAYER2         2
//#define MAGIC_KEY_LAYER3         3
//#define MAGIC_KEY_LAYER4         4
//#define MAGIC_KEY_LAYER5         5
//#define MAGIC_KEY_LAYER6         6
//#define MAGIC_KEY_LAYER7         7
//#define MAGIC_KEY_LAYER8         8
//#define MAGIC_KEY_LAYER9         9
//#define MAGIC_KEY_BOOTLOADER     PAUSE
//#define MAGIC_KEY_LOCK           CAPS
//#define MAGIC_KEY_EEPROM         E
//#define MAGIC_KEY_NKRO           N
//#define MAGIC_KEY_SLEEP_LED      Z

/*
 * Feature disable options
 *  These options are also useful to firmware size reduction.
 */

/* disable debug print */
//#define NO_DEBUG

/* disable print */
//#define NO_PRINT

/* disable action features */
//#define NO_ACTION_LAYER
//#define NO_ACTION_TAPPING
//#define NO_ACTION_ONESHOT
//#define NO_ACTION_MACRO
//#define NO_ACTION_FUNCTION

/*
 * MIDI options
 */

/* Prevent use of disabled MIDI features in the keymap */
//#define MIDI_ENABLE_STRICT 1
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

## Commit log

2018-07-06 raw download of Arduino Basic / Tiny Basic C by Michael Field
2018-07-06 Finished version
    [3dmodel.scad, meckb_da26.fcstd, meckb_da26.stl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]
2018-07-08 make basic use int32_t for numbers, fix basic printnum not working with min value
2018-07-15 Add quickcalc that prints a basic expression
2019-03-19 16 bit different minesweeper boards, minesweeper can print mines left, minesweeper print time when finished

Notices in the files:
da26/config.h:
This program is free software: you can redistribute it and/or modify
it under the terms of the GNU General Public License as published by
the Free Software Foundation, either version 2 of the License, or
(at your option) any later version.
